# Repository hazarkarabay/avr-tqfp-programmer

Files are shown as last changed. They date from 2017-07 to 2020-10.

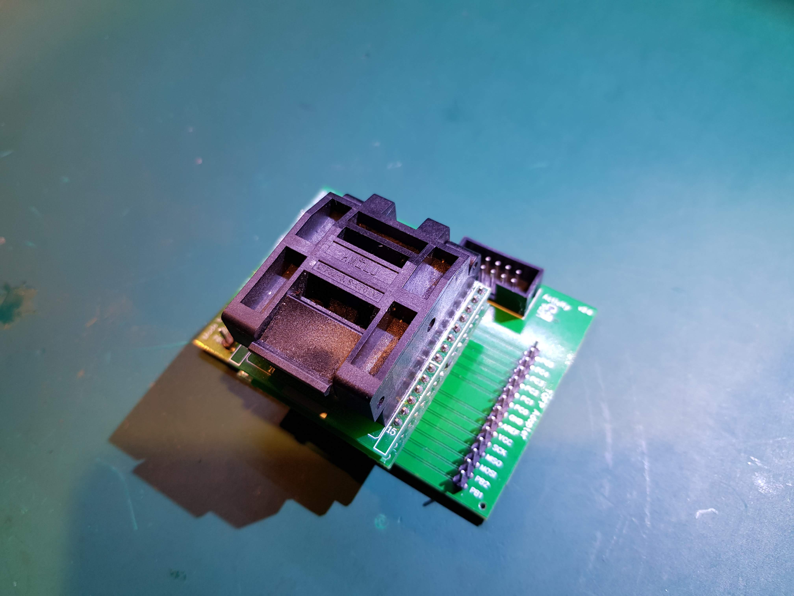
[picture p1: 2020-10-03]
EASYEDA/Pictures/20201003_122633.jpg

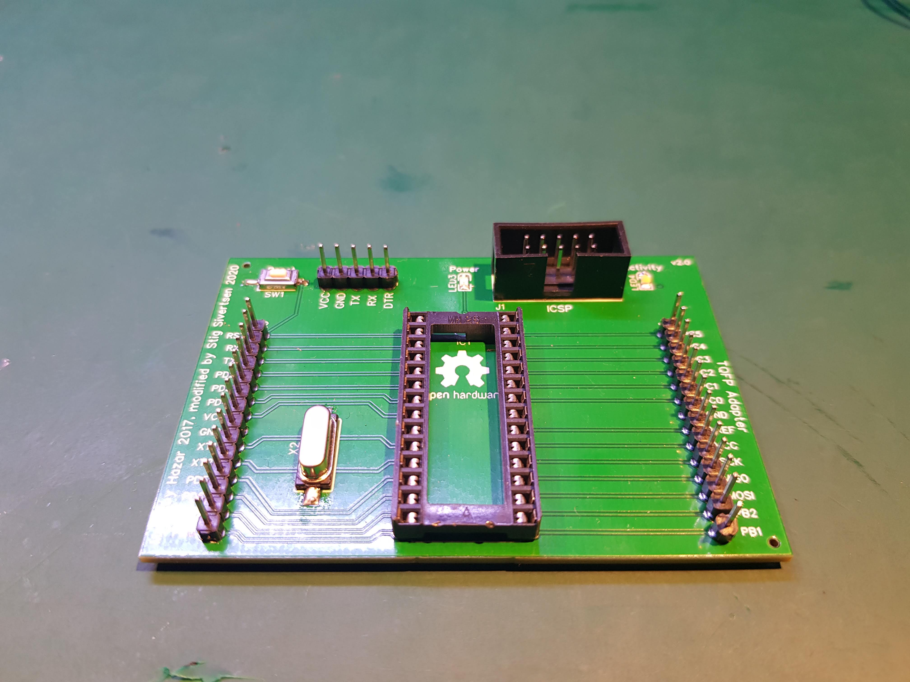
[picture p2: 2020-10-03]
EASYEDA/Pictures/20201003_122325.jpg

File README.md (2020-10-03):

Program TQFP AVR's easily without soldering
=====================

Moving image! (https://www.youtube.com/watch?v=9b8XTmfmTiI)

So, you designed a board that incorporates a SMD AVR and forgot to break out ISP pins. How you gonna upload your code/(if you have serial pins available)bootloader on your microcontroller?

This was my problem. Instead of adding test points to relevant signals, reordering PCBs and messing with pogo pins, I preprogrammed the chips using a TQFP adapter. Here's how I do it.

### You'll need:
- An AVR ISP programmer. You can use a dedicated programmer (Atmel MKII, Atmel ICE3, USBasp etc.) or you can use an Arduino as ISP. If you are not sure, read here: https://learn.sparkfun.com/tutorials/installing-an-arduino-bootloader
- A TQFP to DIP adapter. [I'm using this.](https://www.aliexpress.com/item/Free-shipping-Chip-programmer-TQFP32-QFP32-LQFP32-TO-DIP28-adapter-socket-support-ATMEGA8-series-TL866A-TL866CS/1969735009.html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)
- ISP to TQFP-DIP adapter board. This board goes between your ISP programmer and TQFP adapter. You can get the adapter board from [pcbs.io](https://PCBs.io/share/r1D3D) or make the board with files provided in this repo and using your favorite method (toner transfer, photoresist etc.)

<a href="https://PCBs.io/share/r1D3D">Order from PCBs.io</a>

If you prefer using another PCB manufacturer, feel free to use provided Gerber files.
- AVRDUDE - http://www.nongnu.org/avrdude/

_If your programmer has a ZIF socket (like most Chinese programmers), you don't need that adapter board, you can directly put the TQFP-DIP adapter to your programmers' ZIF socket._    

### How to program your device:
The exact `avrdude` command varies with your programmer and chip type. `avrdude` is a fairly flexible and powerful utility, **please** don't blindly copy/paste the commands provided below, read the `avrdude` manual beforehand. **You can disable your chip with `avrdude` if you mess up fuses and don't know what are you doing.**

>*Word on __disabling__: You can effectively disable the ISP interface **while using** an ISP programmer. If you do this, you can't program your chip over ISP anymore, and it appears [dead](https://hydra-media.cursecdn.com/dota2.gamepedia.com/b/b6/Chatwheel_all_dead.wav). You'll need a real (i.e. high voltage) programmer for restoring at this point (in some situations avrdude can fix that, but do not rely on it). Please don't mess with debugWIRE and RESET fuses if you don't know it. More information can be found at http://www.avrfreaks.net/forum/tutsoft-recovering-locked-out-avr*

After you connect your ISP programmer and adapter, you are ready to program your chip with `avrdude`.
Here is the valid command for **ATMega328P and USBasp** programmer.
```
avrdude -v -patmega328p -cusbasp -e -Ulock:w:0x3F:m -Uefuse:w:0x04:m -Uhfuse:w:0xDE:m -Ulfuse:w:0xFF:m -B100
avrdude -v -patmega328p -cusbasp -e -Ulock:w:0x0F:m -Uflash:w:yoursoftware-withbootloader.hex:i
```

There is 2 seperate commands. First commands only sets the fuse bits and prepares ATMega328P for the actual programming. It sets the crystal, brownout level, disables any locks and does all of it slowly (-B100), because a factory-new ATMega328P comes with its 1MHz internal clock fuse set and USBasp, by default, tries pushing data faster than 250KHz. (ISP frequency is MCU clock/4.) 

Second command is actually programs your hex file and sets the lock fuse to prevent modifying bootloader in your application. It's important, because if you don't set this; you can overwrite/corrupt your bootloader in your application. If you don't use bootloader, you'll need to modify it by your needs.

>**Lock bits explanation:**
There are "fuse bit calculators" on Internet. Here is a example that explains what is going on within the first command. 
http://eleccelerator.com/fusecalc/fusecalc.php?chip=atmega328p&LOW=FF&HIGH=DE&EXTENDED=04&LOCKBIT=3F

### Batch file
I have a batch file to speed up programming multiple AVR's in order. You can see it working on my video. It is very basic, only has a loop and a counter. It serves to my needs and you should customize it if your needs is different. Note that it can't work out of the box, at least the paths needs to be changed.

### 3D-Printed Case for original PCB
A simple 3d-printed case: https://www.thingiverse.com/thing:4529554

### Extended PCB
This is an extension of the original PCB to make it possible to connect sensors and things for testing. PCB files are found in the EASYEDA folder and the home project for this version is located here: https://easyeda.com/sbsivertsen/avr-tqpf-programmer

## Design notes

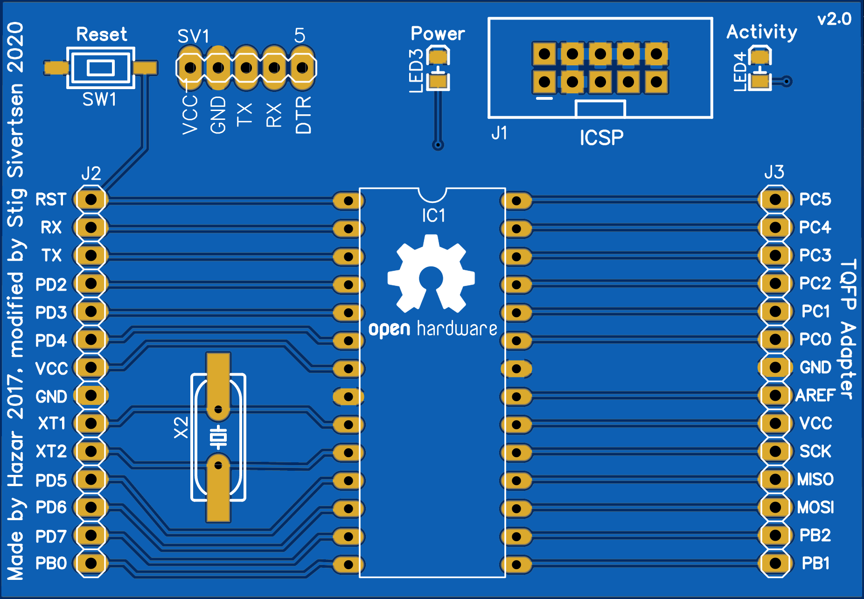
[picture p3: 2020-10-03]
EASYEDA/avr-tqfp-programmer Top side.png

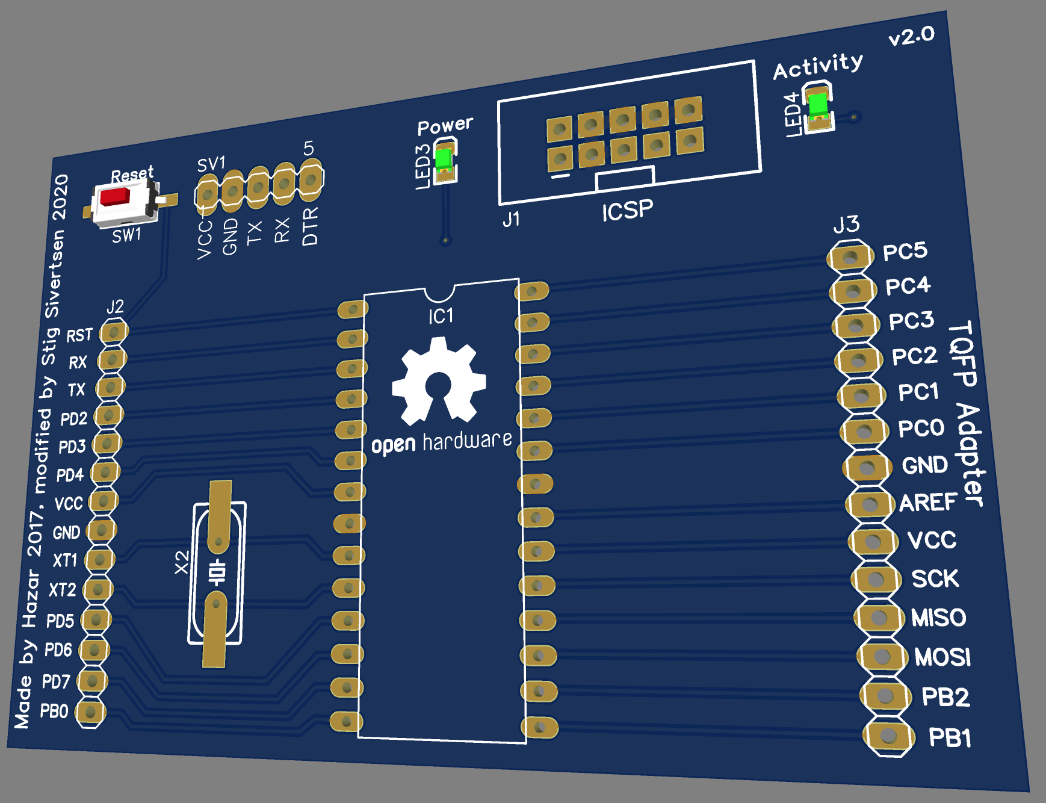
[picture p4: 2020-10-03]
EASYEDA/avr-tqfp-programmer Top side 3D.png

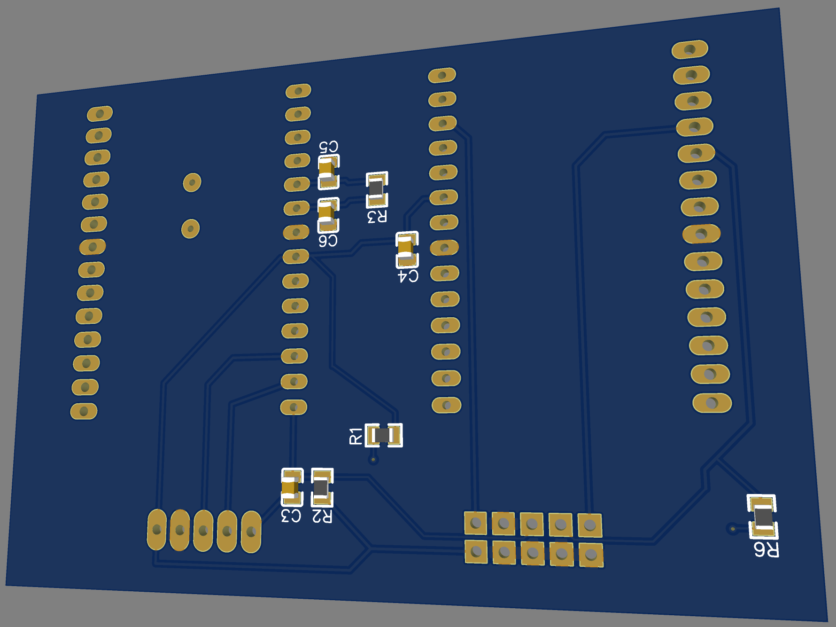
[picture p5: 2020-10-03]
EASYEDA/avr-tqfp-programmer bottom side 3D.png

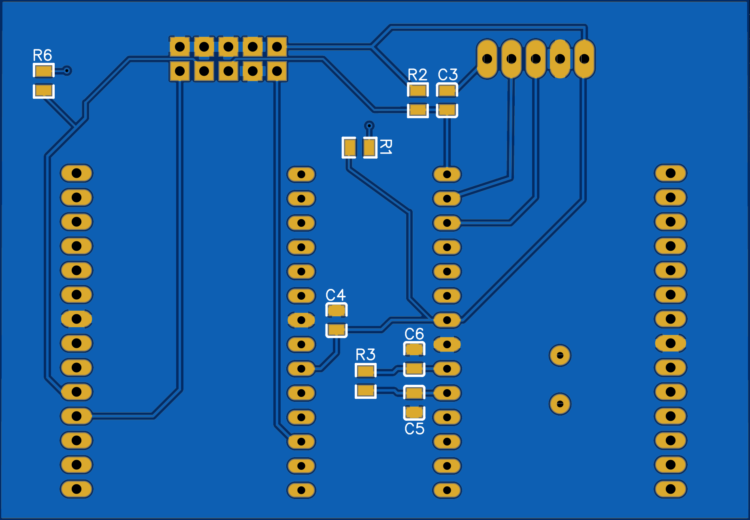
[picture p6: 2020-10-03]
EASYEDA/avr-tqfp-programmer bottom side.png

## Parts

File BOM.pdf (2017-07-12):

Qty | Value | Device | Package | Parts | Description
| 2 330 | R-EU_M0805 | M0805 | R3, R4 | RESISTOR, European symbol
| 2 100n | C-EUC0805K | C0805K | C1, C2 | CAPACITOR, European symbol
| 1 10k | R-EU_M0805 | M0805 | R1 | RESISTOR, European symbol
1 16MHz CRYSTAL | HC49 | XT1 | HC49 Crystal - SMD and through hole combined
| 1 1M | R-EU_M0805 | M0805 | R2 | RESISTOR, European symbol
| 2 22p | C-EUC0805K | C0805K | C3, C4 | CAPACITOR, European symbol
1 | DIL28 | DIL28-6 | IC1 | TQFP Adapter
1 | MA05-1 | MA05-1 | SV1 | PIN HEADER
1 | AVR_SPI | 2X5-SHROUDEDJ1 | AVR 10-pin ICSP Header
2 | LED1206 | LED-1206 | LED1, LED2 LEDs

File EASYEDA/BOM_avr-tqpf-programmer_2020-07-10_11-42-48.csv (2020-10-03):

ID | Name | Designator | Footprint | Quantity | Manufacturer Part | Manufacturer | Supplier | Supplier Part | LCSC Assembly
1 | MA05-1 | SV1 | MA05-1 | 1
2 | CONN_14 | J2,J3 | 1X14 | 2
3 | DIL28 | IC1 | DIL28-6 | 1
4 | AVR_SPI_PROG2PTH2 | J1 | 2X5-SHROUDED | 1
5 | 8MHz | X2 | HC-49SMD | 1 | 49SAT08000122080 | JGHC | LCSC | C479151
6 | D-G080508G1 | LED3,LED4 | LED0805-RD | 2 | D-G080508G1 | ARKLED | LCSC | C107402 | Yes
7 | OSHW-LOGOL | LOGO3 | OSHW-LOGO-L | 1
8 | OPEN_HARDWARE_1 | LOGO2 | LOGO-OPENHARDWARE_8X8 | 1
9 | 330 | R6,R1 | R0805 | 2 | 0805W8J0331T5E | UniOhm | LCSC | C25306
10 | 22pF | C5,C6 | C0805 | 2 | CC0805JRNPO9BN220 | YAGEO | LCSC | C105623
11 | 100nF | C4,C3 | C0805 | 2 | 0805B104J500NT | FH | LCSC | C29926
12 | TSA363G25-250H | SW1 | SW-SMD_L6.5-W3.6-LS8.0 | 1 | TSA363G25-250H | BRIGHT | LCSC | C354942
13 | 10K | R2 | R0805 | 1 | 0805W8J0103T5E | UniOhm | LCSC | C25612
14 | 1M | R3 | R0805 | 1 | ARG05FTC1004 | Viking Tech | LCSC | C218408

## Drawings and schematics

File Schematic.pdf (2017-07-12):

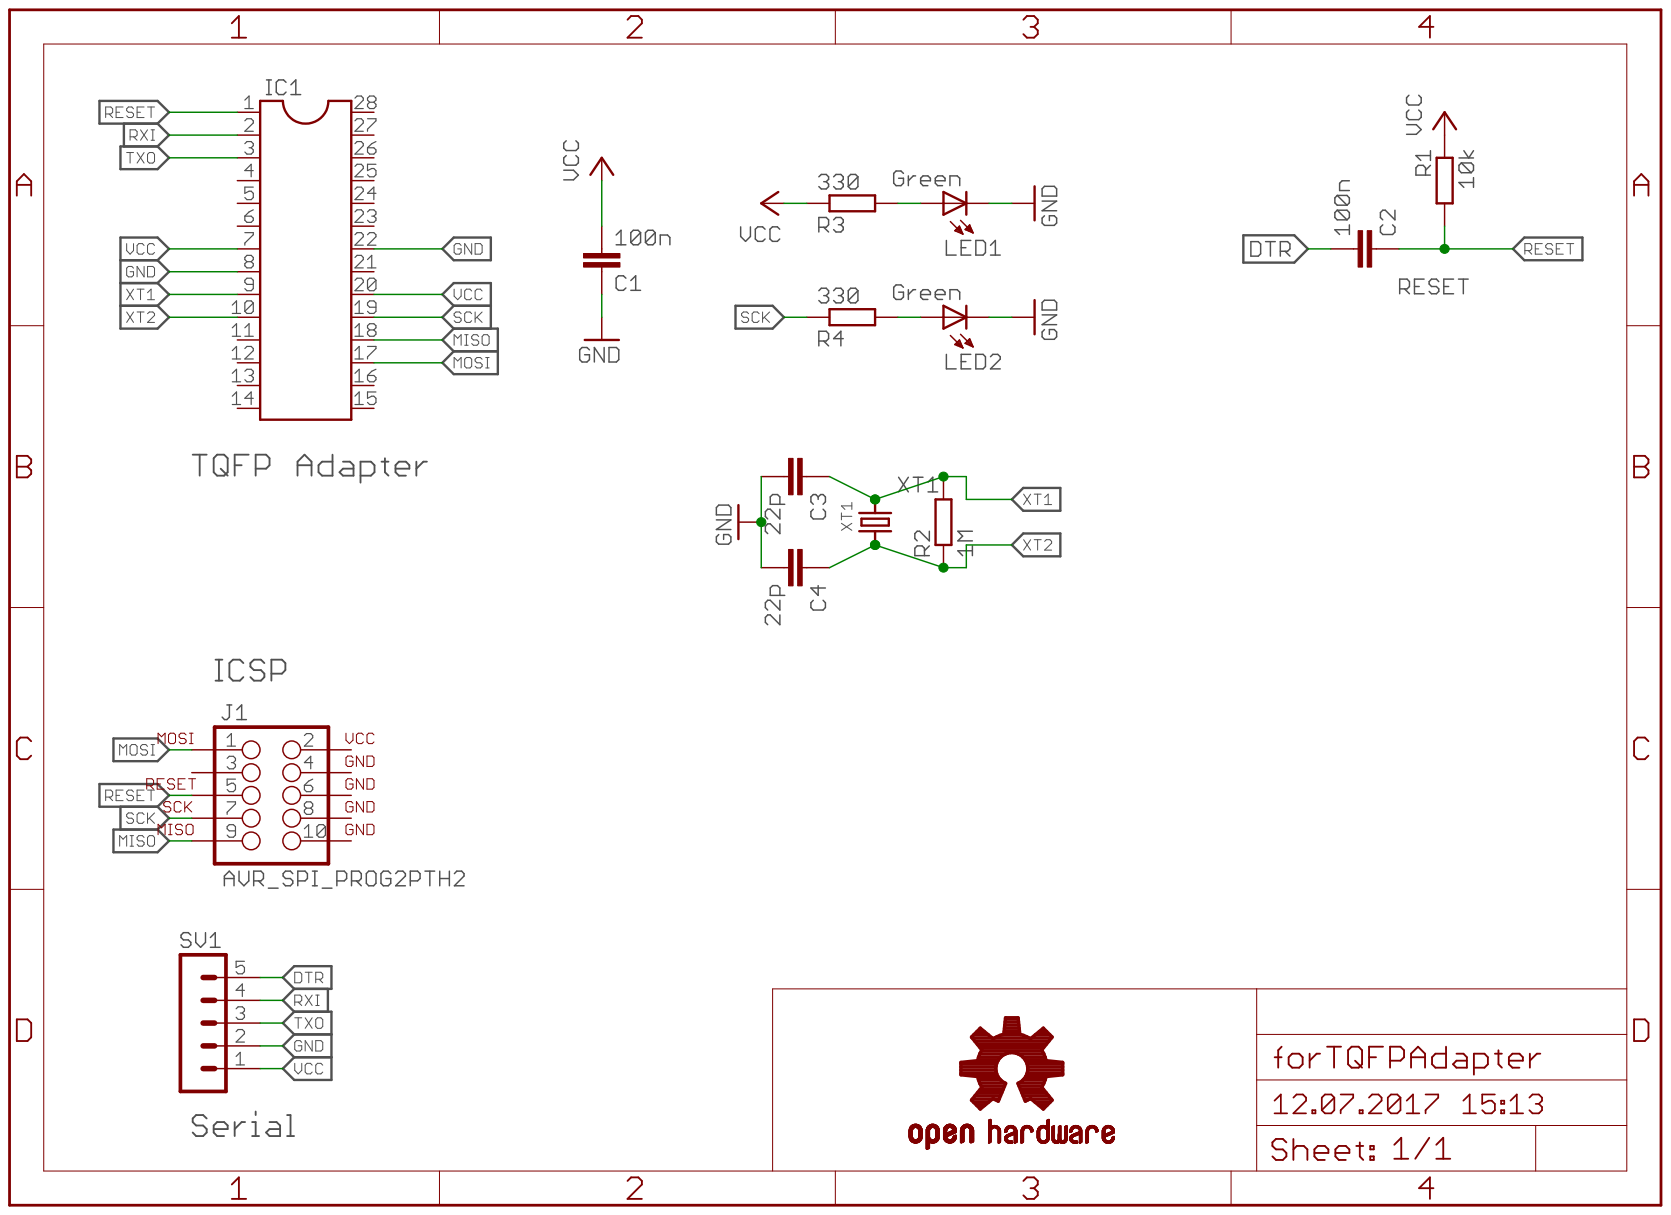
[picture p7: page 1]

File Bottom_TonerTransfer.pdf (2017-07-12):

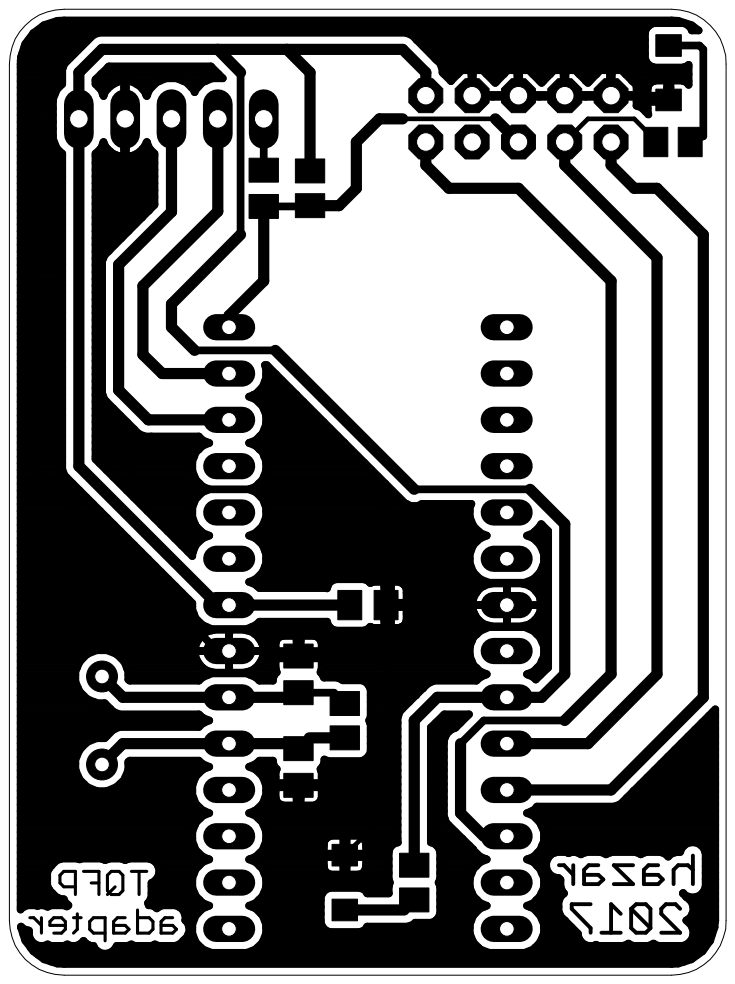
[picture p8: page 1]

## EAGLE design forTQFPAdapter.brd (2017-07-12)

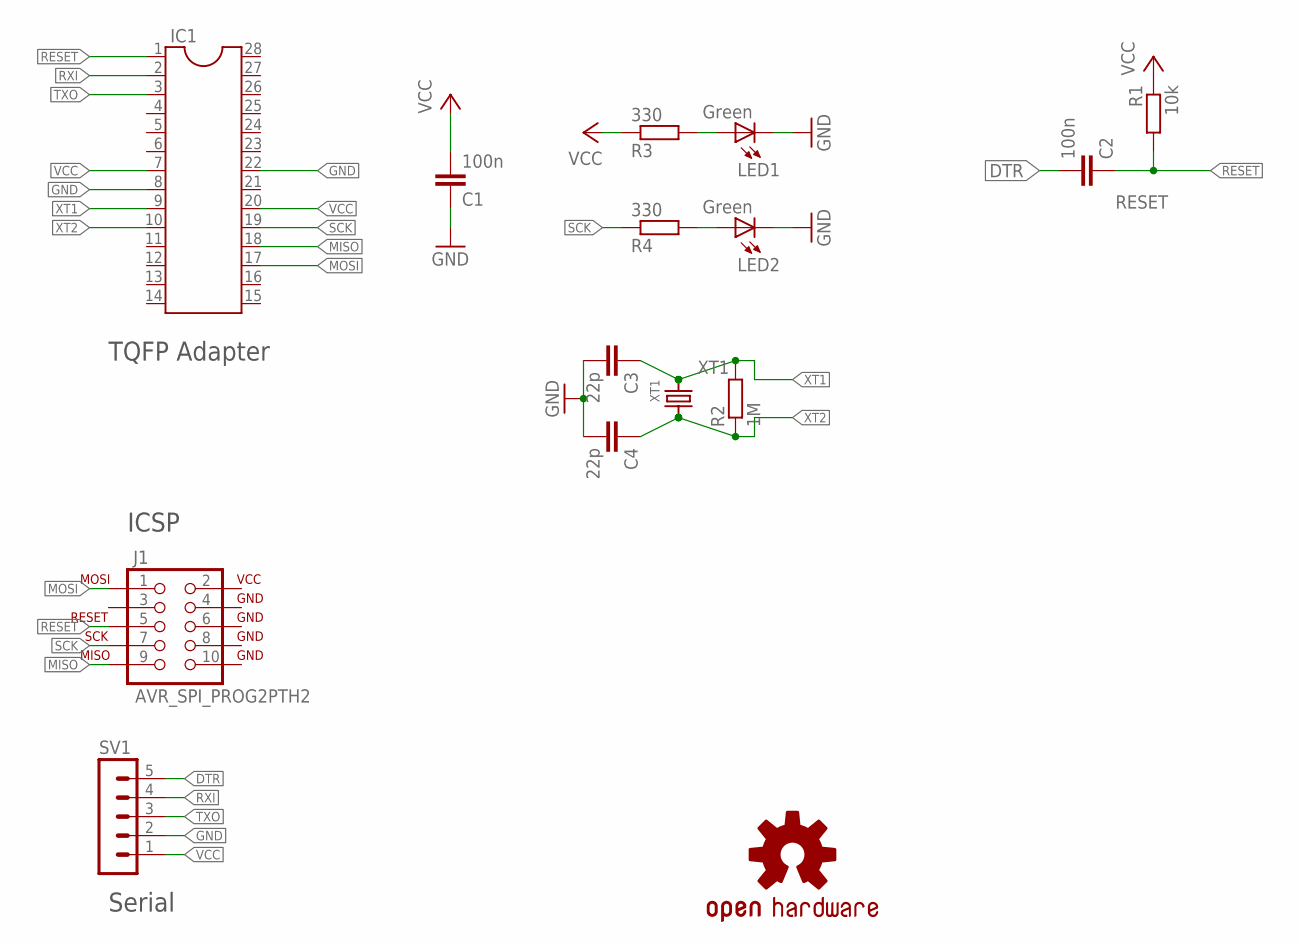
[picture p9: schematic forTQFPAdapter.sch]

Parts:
C1, C2: 100n; C0805K
C3, C4: 22p; C0805K
IC1: DIL28; DIL28-6
J1: AVR_SPI_PROG2PTH2; 2X5-SHROUDED
LED1, LED2: Green; LED-1206
LOGO1: OSHW-LOGOM; OSHW-LOGO-M
R1: 10k; M0805
R2: 1M; M0805
R3, R4: 330; M0805
SV1: MA05-1
XT1: CRYSTAL; HC49

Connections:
DTR: C2.2, SV1.5
GND: C1.1, C3.2, C4.2, IC1.8, IC1.22, J1.4 (GND), J1.6 (GND), J1.8 (GND), J1.10 (GND), LED1.C, LED2.C, SV1.2
MISO: IC1.18, J1.9 (MISO)
MOSI: IC1.17, J1.1 (MOSI)
unnamed: LED2.A, R4.2
unnamed: LED1.A, R3.2
RESET: C2.1, IC1.1, J1.5 (RESET), R1.2
RXI: IC1.2, SV1.4
SCK: IC1.19, J1.7 (SCK), R4.1
TXO: IC1.3, SV1.3
VCC: C1.2, IC1.7, IC1.20, J1.2 (VCC), R1.1, R3.1, SV1.1
XT1: C3.1, IC1.9, R2.2, XT1.11 (1), XT1.12 (1)
XT2: C4.1, IC1.10, R2.1, XT1.21 (2), XT1.22 (2)

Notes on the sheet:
ICSP
Serial
TQFP Adapter

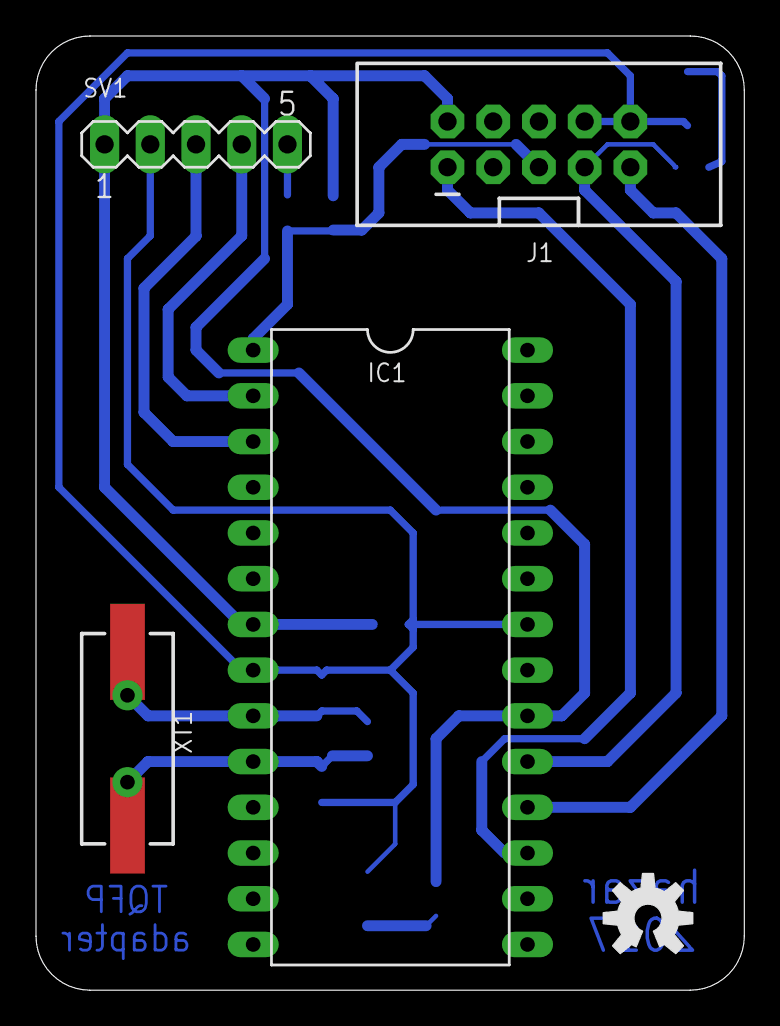
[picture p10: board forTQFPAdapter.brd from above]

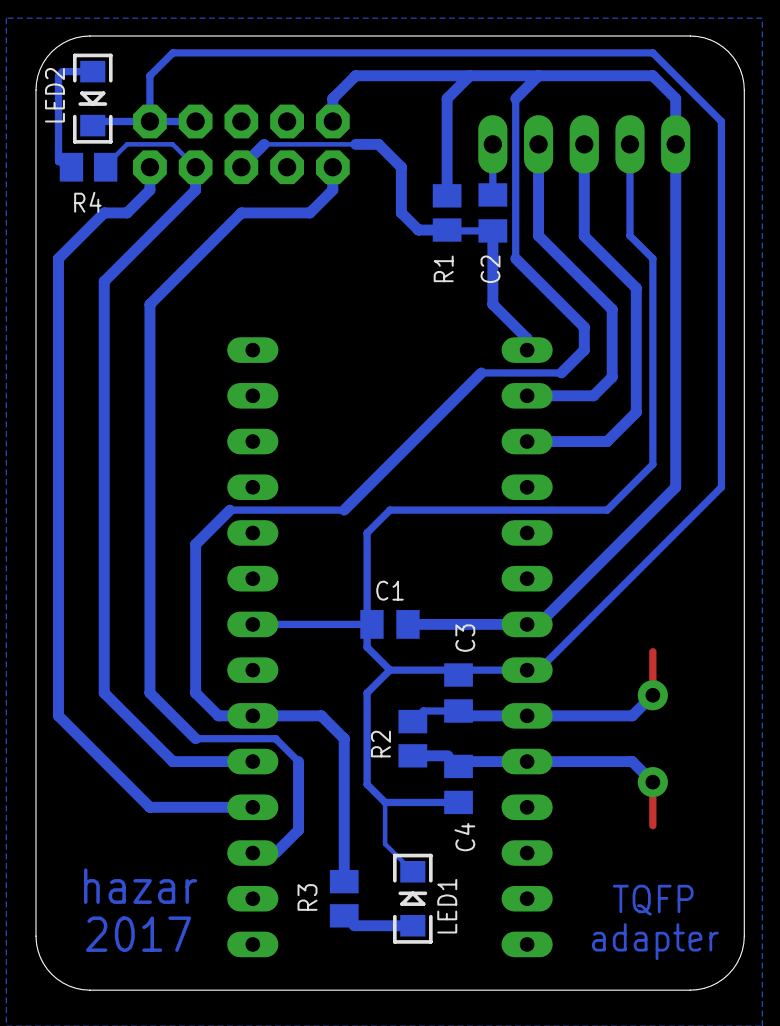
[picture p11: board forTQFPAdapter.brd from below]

Board: 2 copper layers, 39.4 x 53.0 mm, 15 parts (10 on the bottom side), 13 nets.

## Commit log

2020-07-08 Added link to a 3d-printed case to README
2020-07-10 Added an extended pcb, created in Easyeda
    [BOM_avr-tqpf-programmer_2020-07-10_11-42-48.csv, PickAndPlace_avr-tqfp-programmer-DIP28_2020-07-10_11-43-02.csv]
2020-10-03 Added pictures of extended pcb and updated README file.

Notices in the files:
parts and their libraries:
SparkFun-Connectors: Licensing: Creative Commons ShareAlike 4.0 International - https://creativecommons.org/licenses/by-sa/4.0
